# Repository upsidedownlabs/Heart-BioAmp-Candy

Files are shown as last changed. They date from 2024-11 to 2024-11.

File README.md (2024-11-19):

# Heart BioAmp Candy




 


Heart BioAmp Candy is a candy-sized sensor for recording ECG signals easily. It is perfect for students and researchers as it offers reliable and accurate ECG recordings, making heart monitoring accessible and convenient for educational and research purposes.

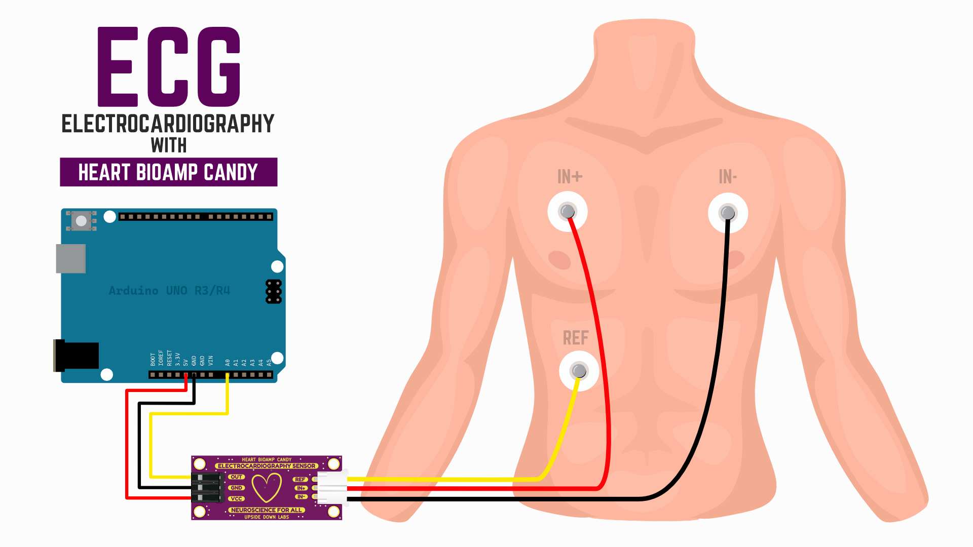
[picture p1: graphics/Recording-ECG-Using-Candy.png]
Heart BioAmp Candy


## Specifications

|Specs | |
| ---- | ---- |
| Input Voltage | 2.7 V - 5 V |
| Fixed Gain | x2157 |
| Bandpass filter | 0.5 - 34 Hz |
| Compatible hardware | Any development board with an ADC (Arduino UNO R3/R4, Arduino Nano, Adafruit QtPy, STM32 Blue Pill, BeagleBone Black, Raspberry Pi Pico, to name just a few) or any standalone ADC of your choice |
| Biopotentials | ECG |
| No. of channels | 1 |
| Electrodes | 3 (Positive, Negative, and Reference) |
| Dimensions | 3.5 x 1.5 cm |
| Open-source | hardware + software |

## Hardware

Heart BioAmp Candy has been created using KiCad and all the design files can be found under [hardware](hardware/) folder, including [Interactive BOM](hardware/bom) file. Images below shows a quick overview of the hardware design.

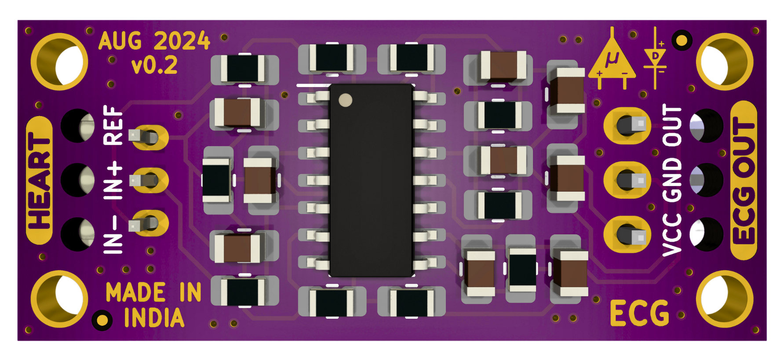
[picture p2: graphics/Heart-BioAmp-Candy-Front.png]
Heart BioAmp Candy


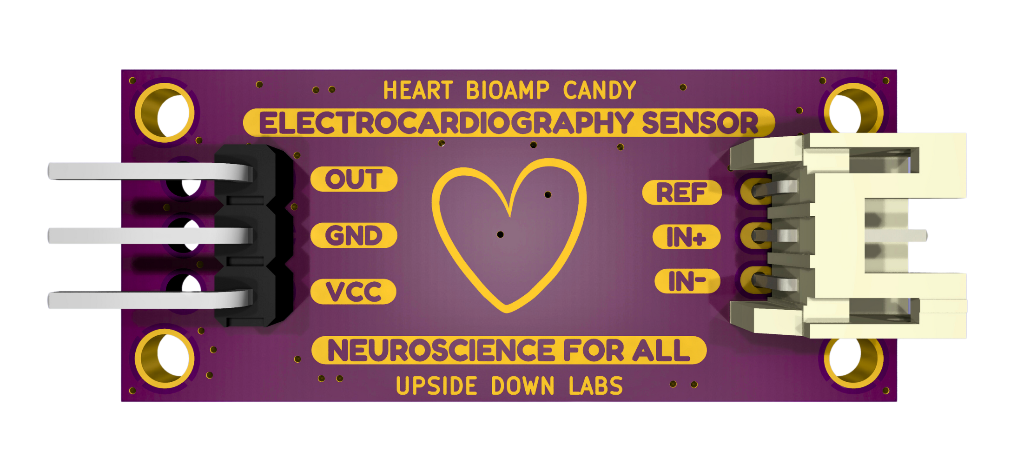
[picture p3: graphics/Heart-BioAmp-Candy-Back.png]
Heart BioAmp Candy


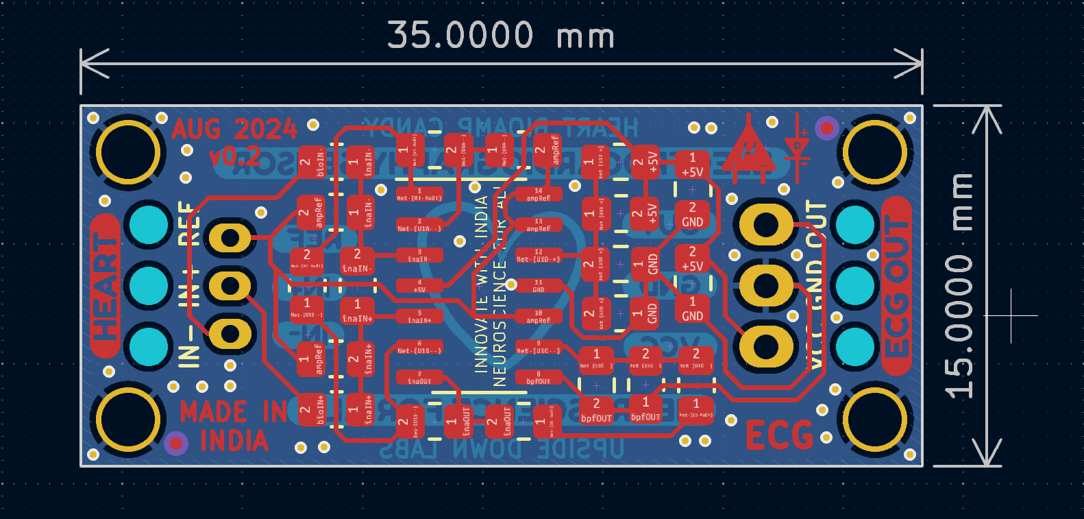
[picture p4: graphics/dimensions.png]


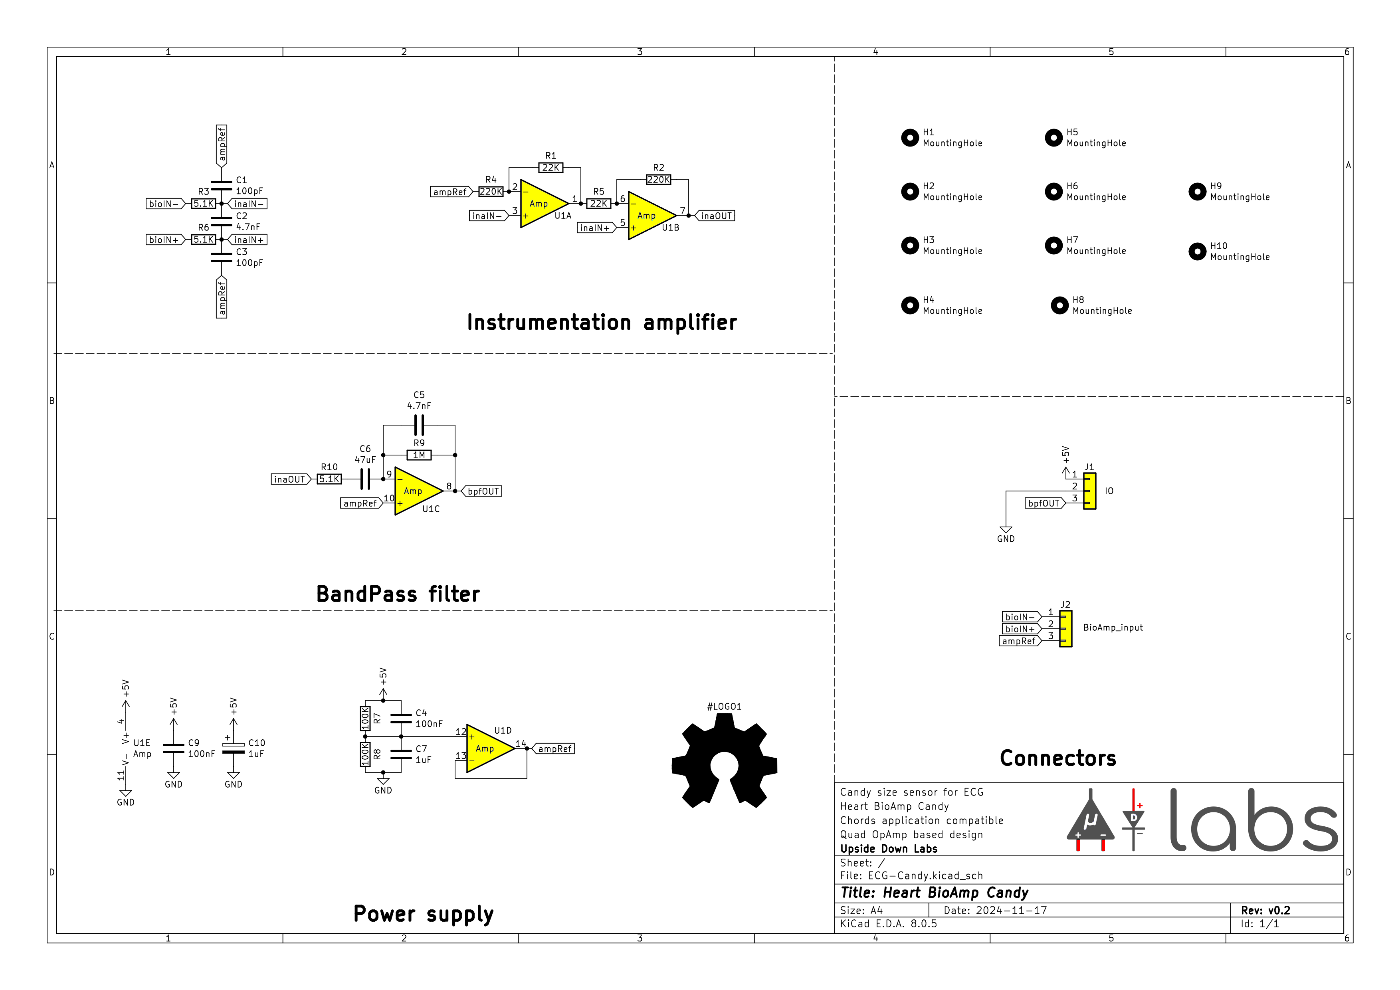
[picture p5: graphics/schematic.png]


## License

CERN Open Hardware License Version 2 - Strongly Reciprocal ([CERN-OHL-S-2.0](https://spdx.org/licenses/CERN-OHL-S-2.0.html)).

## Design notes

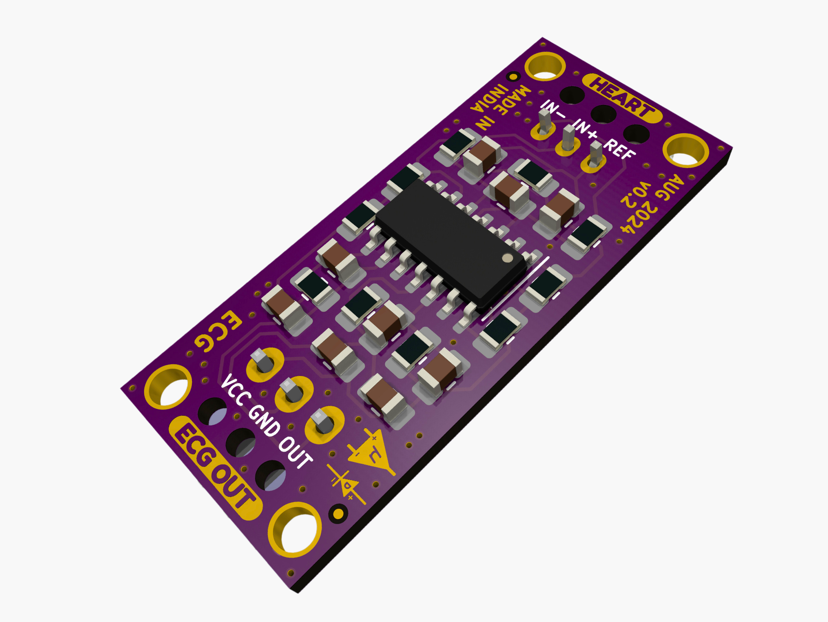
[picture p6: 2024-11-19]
graphics/Heart-BioAmp-Candy-Angled.png

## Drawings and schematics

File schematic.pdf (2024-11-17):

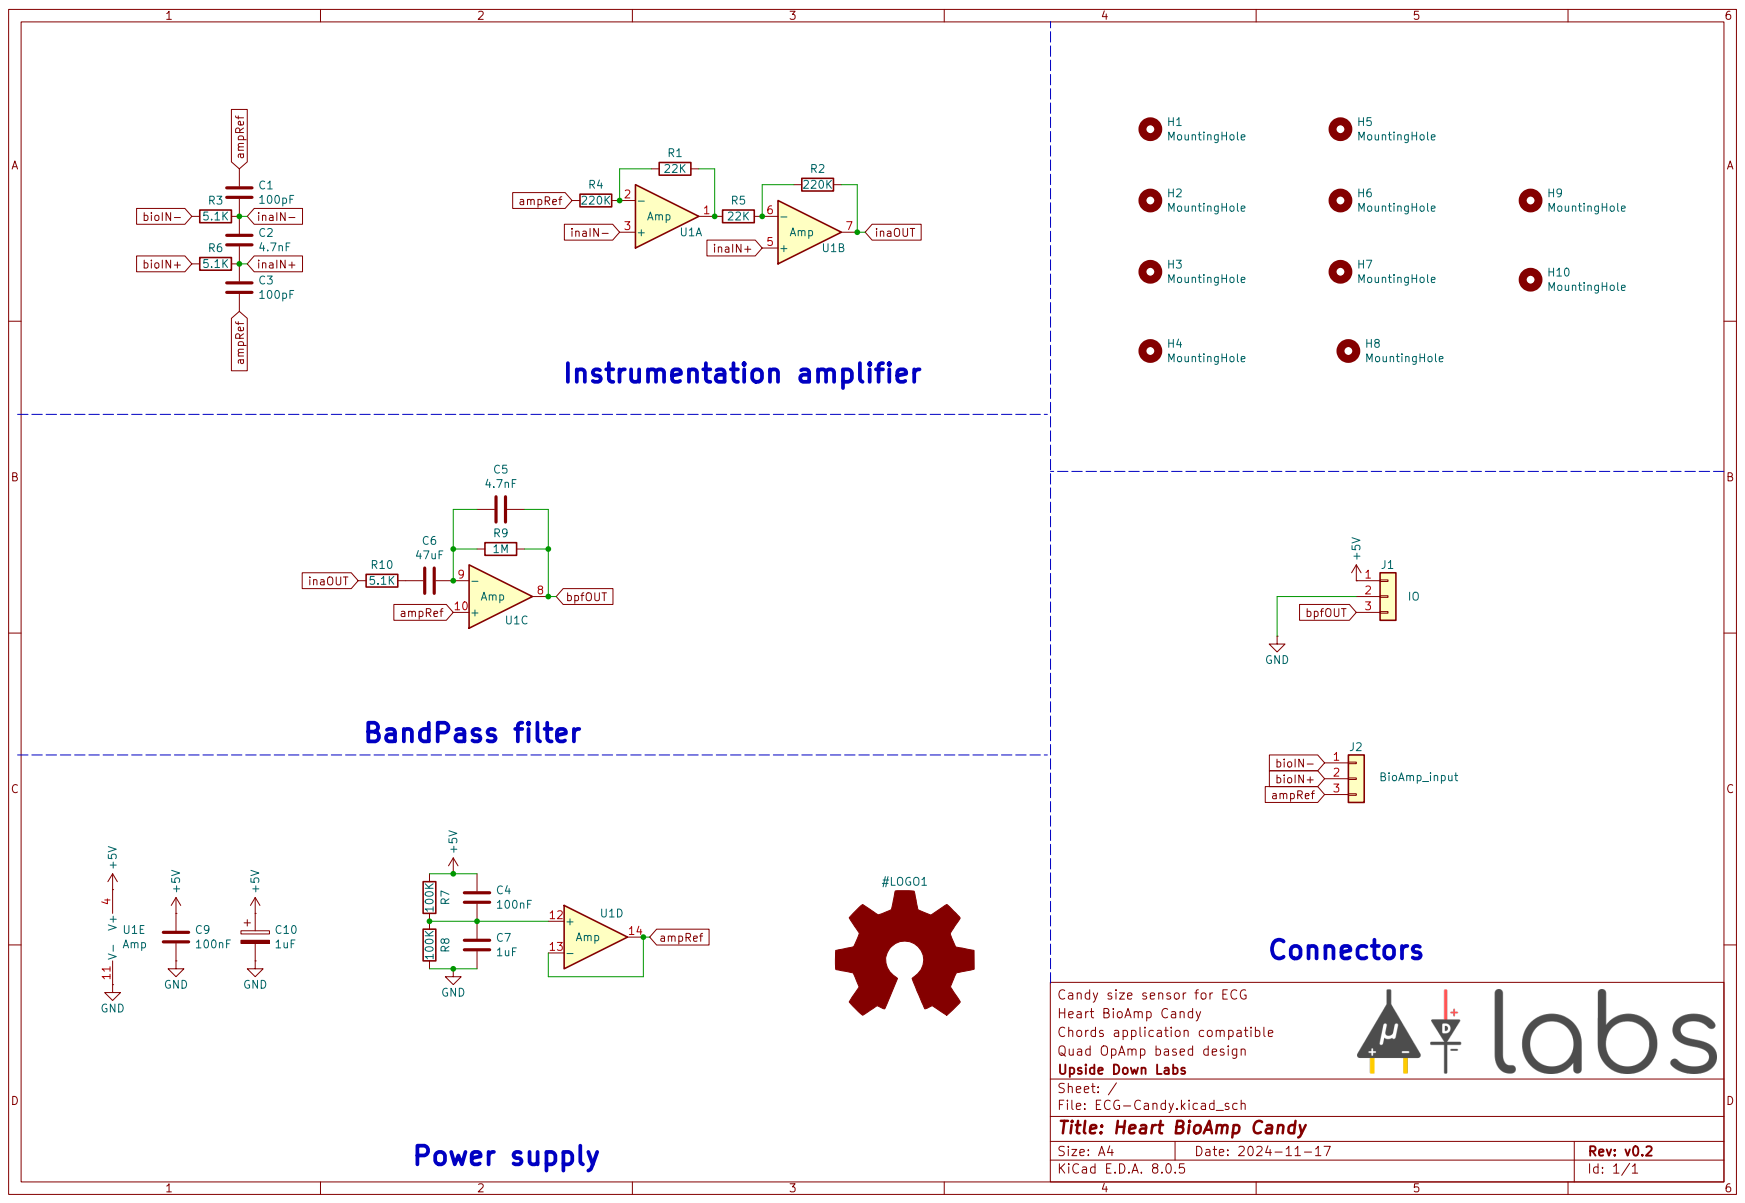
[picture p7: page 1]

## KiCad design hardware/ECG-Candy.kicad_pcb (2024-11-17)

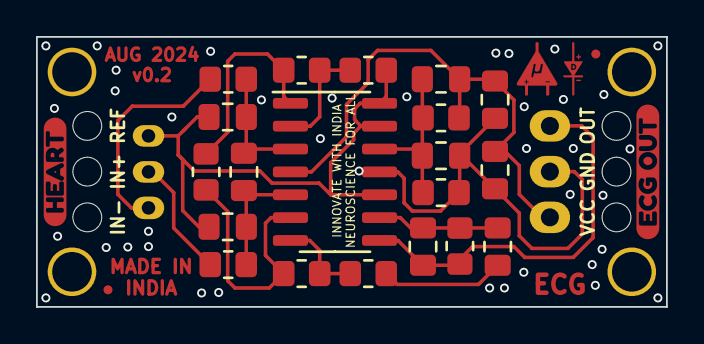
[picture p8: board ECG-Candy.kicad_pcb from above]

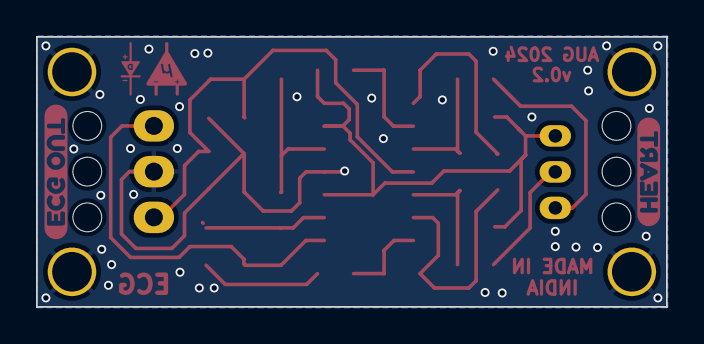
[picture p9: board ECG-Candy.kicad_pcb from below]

Board: 2 copper layers, 35.0 x 15.0 mm, 42 parts (10 on the bottom side), 13 nets.

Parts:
C1, C3: 100pF; C_0805_2012Metric_Pad1.18x1.45mm_HandSolder
C2, C5: 4.7nF; C_0805_2012Metric_Pad1.18x1.45mm_HandSolder
C4, C9: 100nF; C_0805_2012Metric_Pad1.18x1.45mm_HandSolder
C6: 47uF; C_0805_2012Metric_Pad1.18x1.45mm_HandSolder
C7, C10: 1uF; C_0805_2012Metric_Pad1.18x1.45mm_HandSolder
H1, H2, H3, H4, H5, H6, H7, H8, H9, H10: MountingHole; MountingHole_2.1mm
J1: IO; PinHeader_1x03_P2.54mm_Horizontal
J2: BioAmp_input; JST_PH_S3B-PH-K_1x03_P2.00mm_Horizontal
R1, R5: 22K; R_0805_2012Metric_Pad1.20x1.40mm_HandSolder
R2, R4: 220K; R_0805_2012Metric_Pad1.20x1.40mm_HandSolder
R3, R6, R10: 5.1K; R_0805_2012Metric_Pad1.20x1.40mm_HandSolder
R7, R8: 100K; R_0805_2012Metric_Pad1.20x1.40mm_HandSolder
R9: 1M; R_0805_2012Metric_Pad1.20x1.40mm_HandSolder
U1: Amp; SOIC-14_3.9x8.7mm_P1.27mm
kibuzzard-66A7D726: G***; kibuzzard-66A7D726
kibuzzard-66A7D805: G***; kibuzzard-66A7D805
kibuzzard-66AFEDBF: G***; kibuzzard-66AFEDBF
kibuzzard-66AFEDE1: G***; kibuzzard-66AFEDE1
kibuzzard-66AFEDEA: G***; kibuzzard-66AFEDEA
kibuzzard-66AFEDF0: G***; kibuzzard-66AFEDF0
kibuzzard-66AFEDFC: G***; kibuzzard-66AFEDFC
kibuzzard-66AFEE03: G***; kibuzzard-66AFEE03
kibuzzard-66AFEE09: G***; kibuzzard-66AFEE09
kibuzzard-66AFEE10: G***; kibuzzard-66AFEE10

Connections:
+5V: C4.2, C9.2, C10.1, R7.2, U1.4 (V+)
GND: C7.1, C9.1, C10.2, R8.1, U1.11 (V-)
unnamed: C6.1, R10.1
unnamed: R1.1, R5.2, U1.1
unnamed: R1.2, R4.1, U1.2 (-)
unnamed: R2.2, R5.1, U1.6 (-)
unnamed: C5.1, C6.2, R9.2, U1.9 (-)
unnamed: C4.1, C7.2, R7.1, R8.2, U1.12 (+)
ampRef: C1.2, C3.1, R4.2, U1.10 (+), U1.13 (-), U1.14
bpfOUT: C5.2, R9.1, U1.8
inaIN+: C2.1, C3.2, R6.1, U1.5 (+)
inaIN-: C1.1, C2.2, R3.1, U1.3 (+)
inaOUT: R2.1, R10.2, U1.7
